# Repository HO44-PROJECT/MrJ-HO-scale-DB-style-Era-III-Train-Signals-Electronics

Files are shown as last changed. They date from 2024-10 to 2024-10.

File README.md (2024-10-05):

# Railway HO project Signals and electronics for my HO scale railway project

This is my own project for building model railway HO scale (1:87) Deutsche Bundesbahn (DB) style Era III (1945-1970) Train Signals following this specification.

This is part of a complete project involving:

- 3D printing ([Maker World](https://makerworld.com/en/models/682526#profileId-611046))
- Electronics (PCB design and soldering) ([github](https://github.com/HO44-PROJECT/MrJ-HO-scale-DB-style-Era-III-Train-Signals-Electronics))
- Arduino code (demo, DCC and JMRI integration) ([github](https://github.com/HO44-PROJECT/MrJ-HO-scale-DB-style-Era-III-Train-Signals-Arduino-Demo-Code))

# Resources

[wikipedia signals in Germany](https://en.wikipedia.org/wiki/Railway_signals_in_Germany)

These sites were a great source of inspiration:
* [stummi forum (DE)](https://www.stummiforum.de/t174376f21-Viessman-Signalbr-cke-mit-Arduino-gesteuert.html)
* [digital bahn (DE)] (https://www.digital-bahn.de/info_kompo/signale.htm)

# Project

This project contains Kicad project files and gerber to build PCBs using 1.8mm LEDs.

This PCB uses charlieplexing to reduce the number of wires. It is possible to build a block signal, input signal, or output signal with this PCB.
I designed my own wiring path to avoid using the POV effect to light multiple LEDs. Each situation for each signal is a simple combination of HIGH and LOW signals on all 4 pins.

It's possible to reduce the number of wires for the "Block Signal" (only 2 wires required) and the "Entry Signal" (only 3 wires required). See [documentation/] (documentation/)

I also need a special breadboard version to ease tests. This version allows soldering of resistors.

The **gerber.zip** files are enough to build the PCB from a manufacturer such as [jlcpcb](https://jlcpcb.com/). See [release/] (release/) directory.

# History

The version 2 is smaller than the version 1.
It solves the "shunting signal" Hp0 + Sh1 did not work because the right white LED did not light up.

This v3 is a better version as it fixes a distributed current problem.

# Source

The [source/] directory contains Kicad files

# BOM:
* a PCB per signal. I ordered mine 0.8mm thickness from jlcpcb.com simply by uploading the gerber.zip file.
* 2 to 4 60 to 100 ohm resistors 1/4 W from everywhere
* 1.8mm LEDs. I bought mine from aliexpress.com.

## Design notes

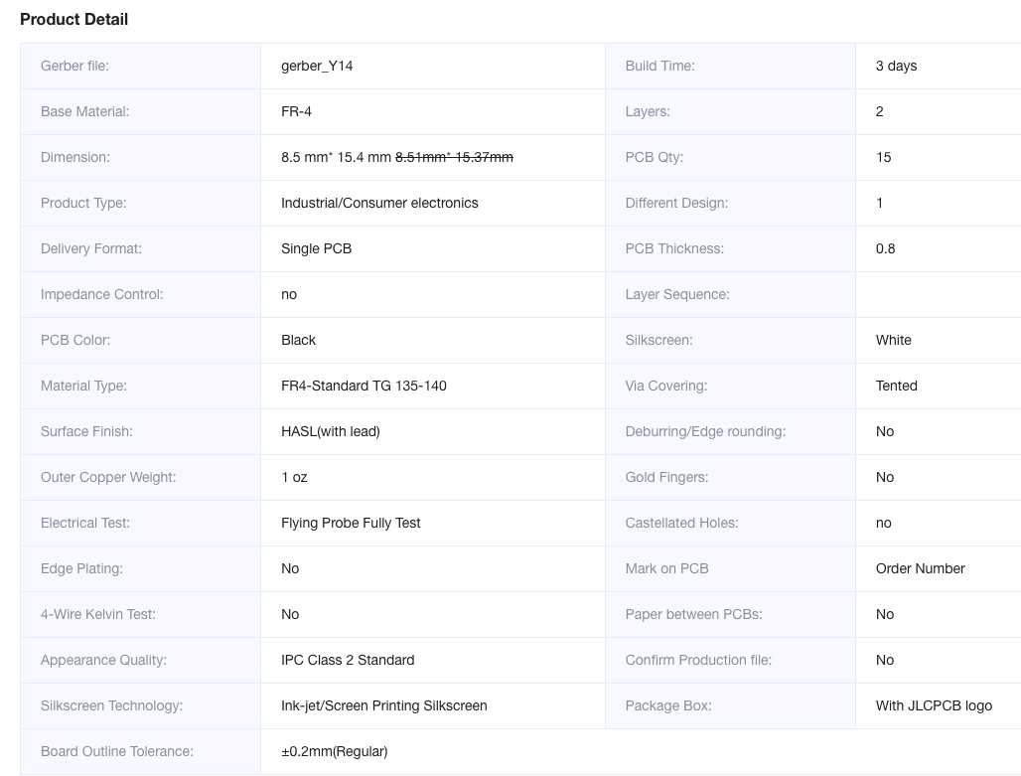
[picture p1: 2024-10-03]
release/kicad_pcb_ho_db_signals_v3 - pcb parameters.png

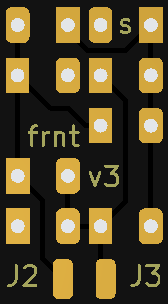
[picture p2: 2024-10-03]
documentation/MrJ HO scale DB Signals Era III - pcb - front - v3.png

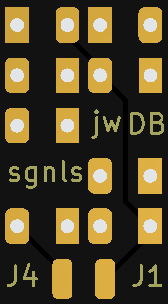
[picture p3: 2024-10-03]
documentation/MrJ HO scale DB Signals Era III - pcb - back - v3.png

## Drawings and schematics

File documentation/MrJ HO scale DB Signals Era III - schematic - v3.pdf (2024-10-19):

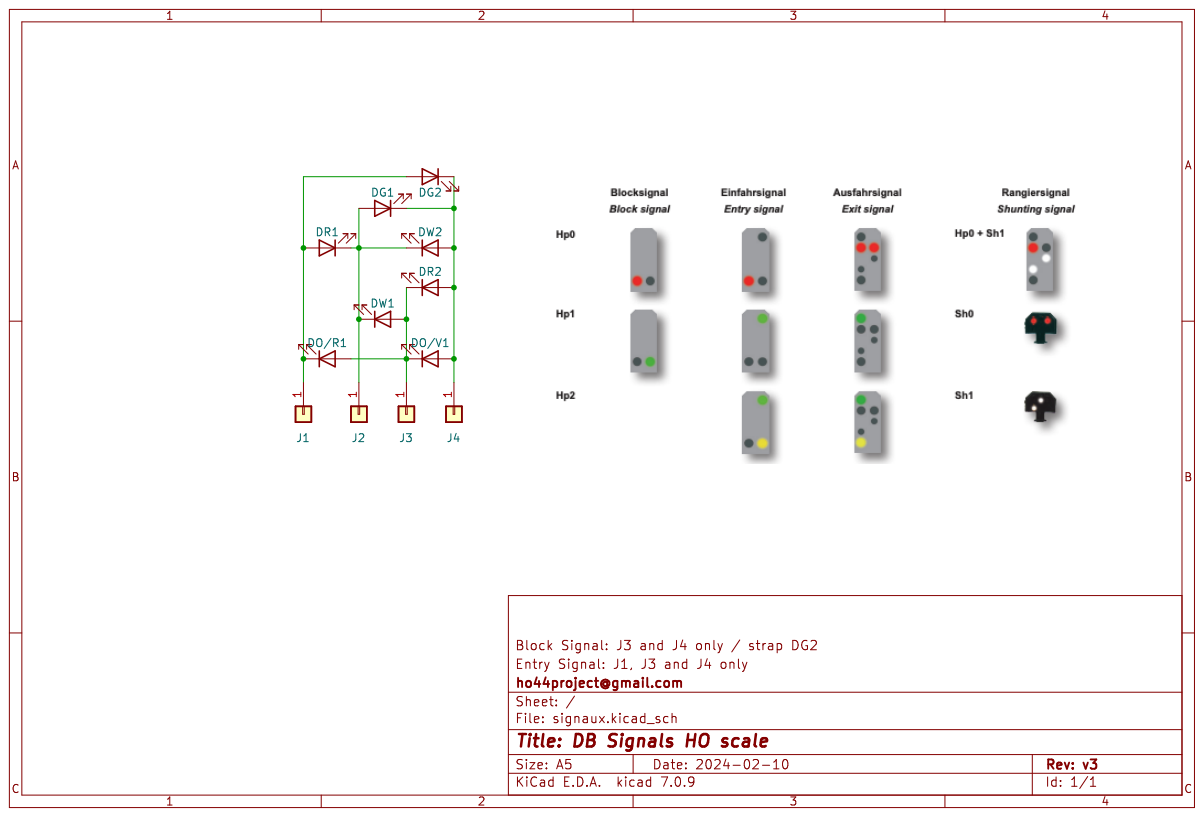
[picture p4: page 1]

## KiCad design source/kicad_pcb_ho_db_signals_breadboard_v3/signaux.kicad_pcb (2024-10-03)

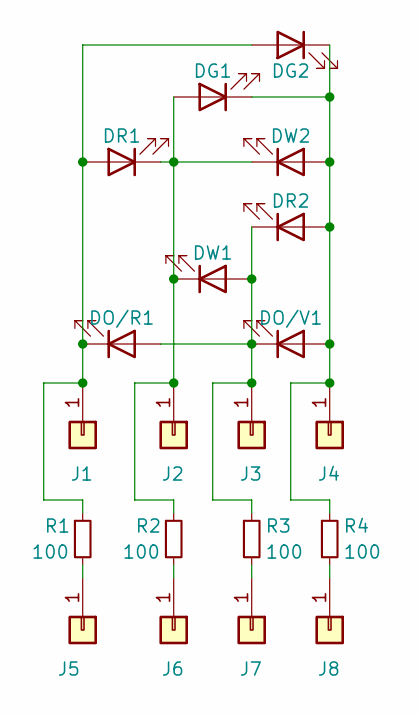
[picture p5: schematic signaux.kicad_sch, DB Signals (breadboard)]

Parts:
DG1, DG2: LED; LED_D1.8mm_W3.3mm_H2.4mm_mine
DO/R1: LED; LED_D1.8mm_W3.3mm_H2.4mm_mine
DO/V1: LED; LED_D1.8mm_W3.3mm_H2.4mm_mine
DR1, DR2: LED; LED_D1.8mm_W3.3mm_H2.4mm_mine
DW1, DW2: LED; LED_D1.8mm_W3.3mm_H2.4mm_mine
J1, J2, J3, J4: Conn_01x01; SolderWirePad_1x01_SMD_1x2mm
J5, J6, J7, J8: Conn_01x01; Pin_D0.9mm_L10.0mm_W2.4mm_FlatFork
R1, R2, R3, R4: 100; R_Axial_DIN0204_L3.6mm_D1.6mm_P7.62mm_Horizontal

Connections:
unnamed: DG1.2 (A), DR1.1 (K), DW1.1 (K), DW2.1 (K), J2.1, R2.1
unnamed: DG1.1 (K), DG2.1 (K), DO/V1.2 (A), DR2.2 (A), DW2.2 (A), J4.1, R4.1
unnamed: DG2.2 (A), DO/R1.1 (K), DR1.2 (A), J1.1, R1.1
unnamed: DO/R1.2 (A), DO/V1.1 (K), DR2.1 (K), DW1.2 (A), J3.1, R3.1
unnamed: J5.1, R1.2
unnamed: J6.1, R2.2
unnamed: J7.1, R3.2
unnamed: J8.1, R4.2

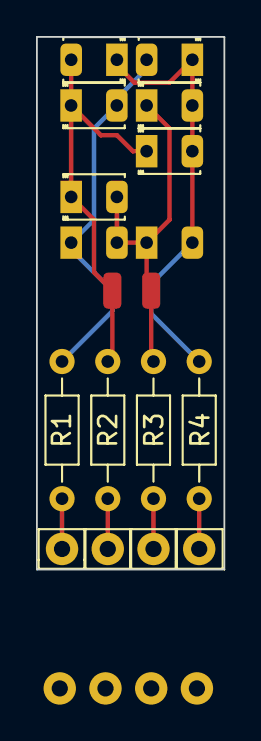
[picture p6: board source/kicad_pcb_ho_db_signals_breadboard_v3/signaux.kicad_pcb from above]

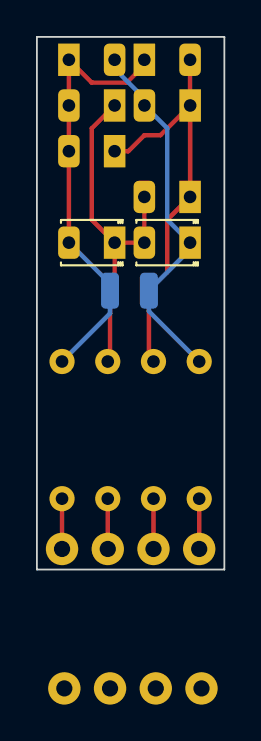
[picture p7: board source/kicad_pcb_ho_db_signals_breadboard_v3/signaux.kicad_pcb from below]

Board: 2 copper layers, 10.4 x 29.6 mm, 20 parts (4 on the bottom side), 8 nets.

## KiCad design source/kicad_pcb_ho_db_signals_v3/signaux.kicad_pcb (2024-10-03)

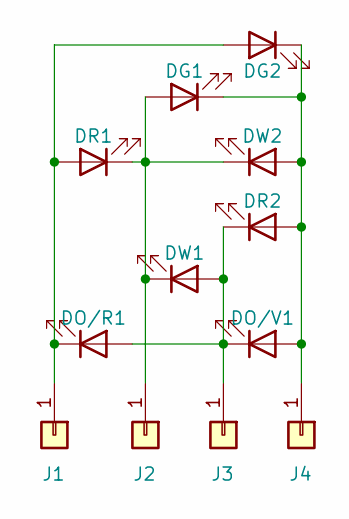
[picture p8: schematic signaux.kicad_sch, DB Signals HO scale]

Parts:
DG1, DG2: LED; LED_D1.8mm_W3.3mm_H2.4mm_mine
DO/R1: LED; LED_D1.8mm_W3.3mm_H2.4mm_mine
DO/V1: LED; LED_D1.8mm_W3.3mm_H2.4mm_mine
DR1, DR2: LED; LED_D1.8mm_W3.3mm_H2.4mm_mine
DW1, DW2: LED; LED_D1.8mm_W3.3mm_H2.4mm_mine
J1, J2, J3, J4: Conn_01x01; SolderWirePad_1x01_SMD_1x2mm

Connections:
unnamed: DG1.2 (A), DR1.1 (K), DW1.1 (K), DW2.1 (K), J2.1
unnamed: DG1.1 (K), DG2.1 (K), DO/V1.2 (A), DR2.2 (A), DW2.2 (A), J4.1
unnamed: DG2.2 (A), DO/R1.1 (K), DR1.2 (A), J1.1
unnamed: DO/R1.2 (A), DO/V1.1 (K), DR2.1 (K), DW1.2 (A), J3.1

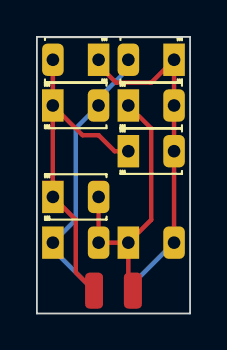
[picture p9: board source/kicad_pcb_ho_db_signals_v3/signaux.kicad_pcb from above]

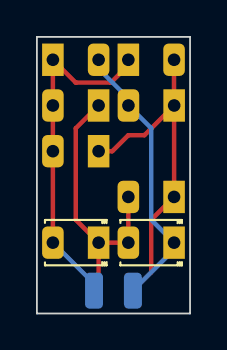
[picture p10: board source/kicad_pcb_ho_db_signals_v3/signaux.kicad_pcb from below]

Board: 2 copper layers, 8.5 x 15.4 mm, 12 parts (4 on the bottom side), 4 nets.

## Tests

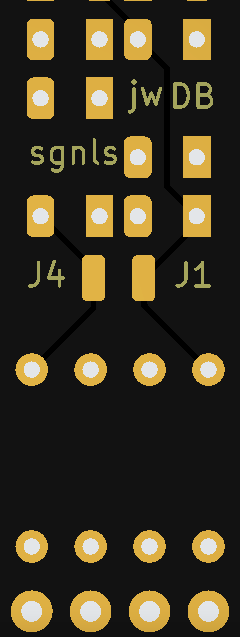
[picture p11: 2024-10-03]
documentation/MrJ HO scale DB Signals Era III - pcb - test back - v3.png

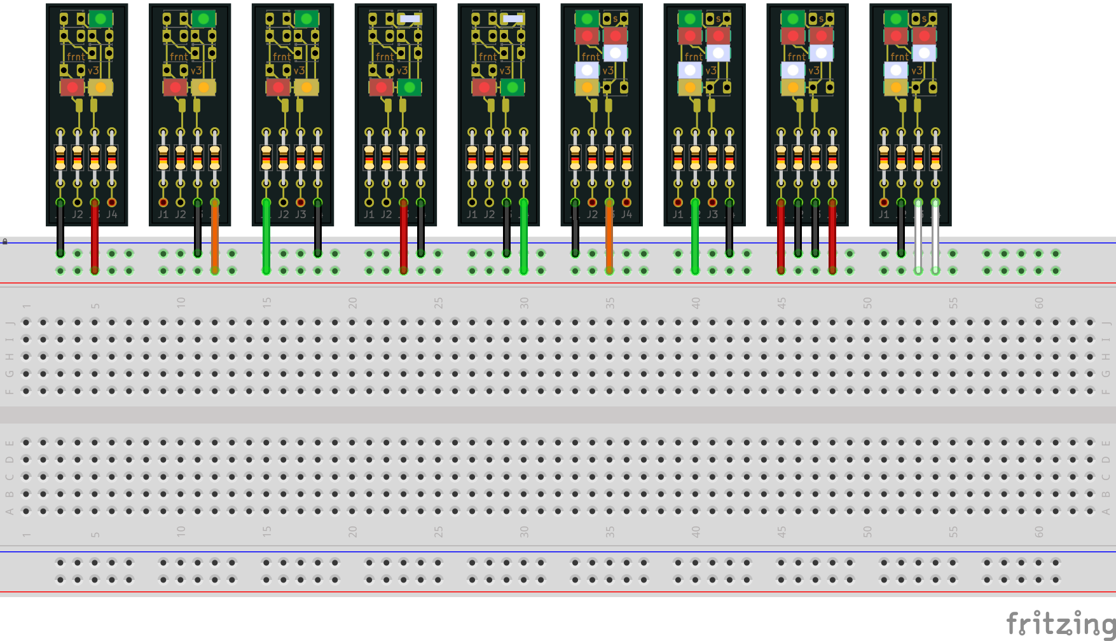
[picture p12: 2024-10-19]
documentation/MrJ HO scale DB Signals Era III - breadboard - test - v3.png

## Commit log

2024-02-17 first shot
    [signaux.kicad_pcb, signaux.kicad_sch]
2024-10-03 gerber files
